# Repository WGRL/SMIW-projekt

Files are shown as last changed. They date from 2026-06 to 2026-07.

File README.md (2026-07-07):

Schematy i płytki PCB obejmują 3 projekty:
 - Moduł m5 Stamp-S3, zasilanie 12V i step downy na 5V i 3V3, potrzymanie akumulatorowe i ładowarkę opartą na LM317 + sterowanie źródłem zasilania
   Screenshot from 2026-07-08 00-59-42

 - Moduł czytnika kart micro sd (SPI) i pamięć FRAM
   Screenshot from 2026-07-08 01-00-04

 - Moduł sterowania silnikiem 12V, złącze silnika i enkoder
   Screenshot from 2026-07-08 00-59-53

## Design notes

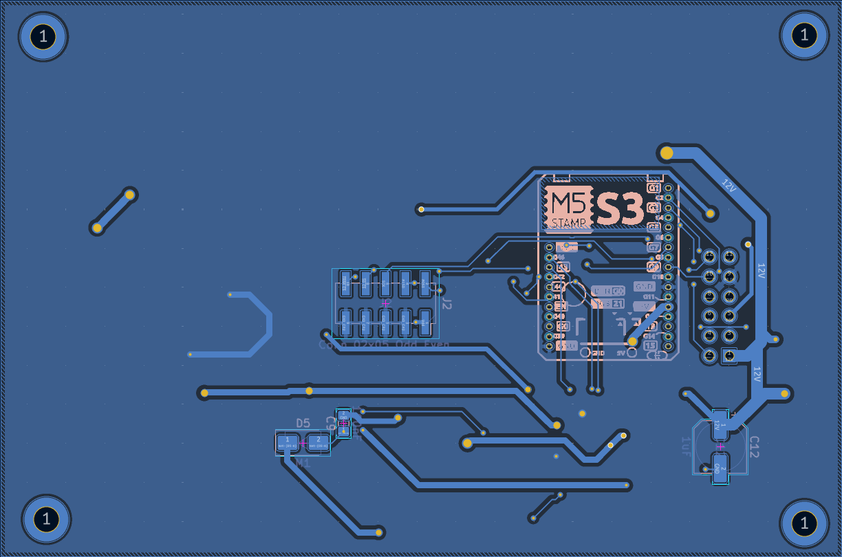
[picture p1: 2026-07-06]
img/PCB/Screenshot from 2026-07-06 23-42-25.png

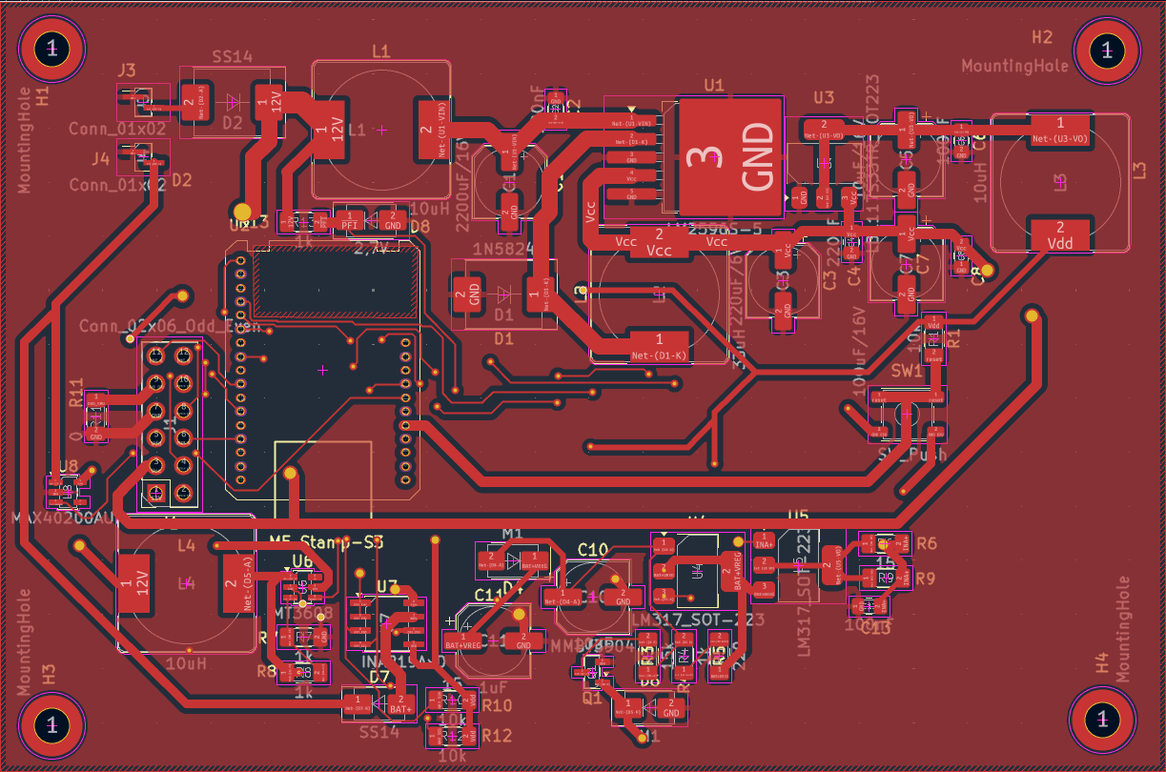
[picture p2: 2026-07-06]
img/PCB/Screenshot from 2026-07-06 23-42-44.png

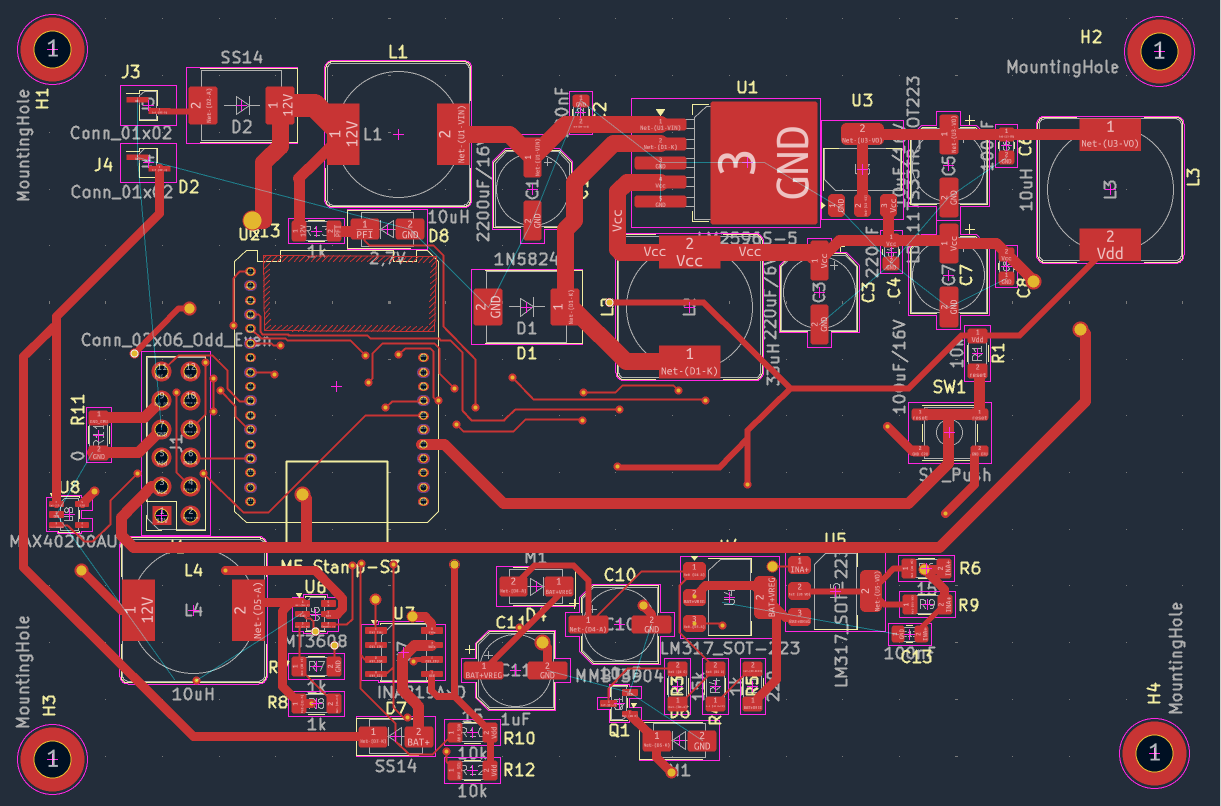
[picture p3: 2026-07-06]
img/PCB/Screenshot from 2026-07-06 23-42-52.png

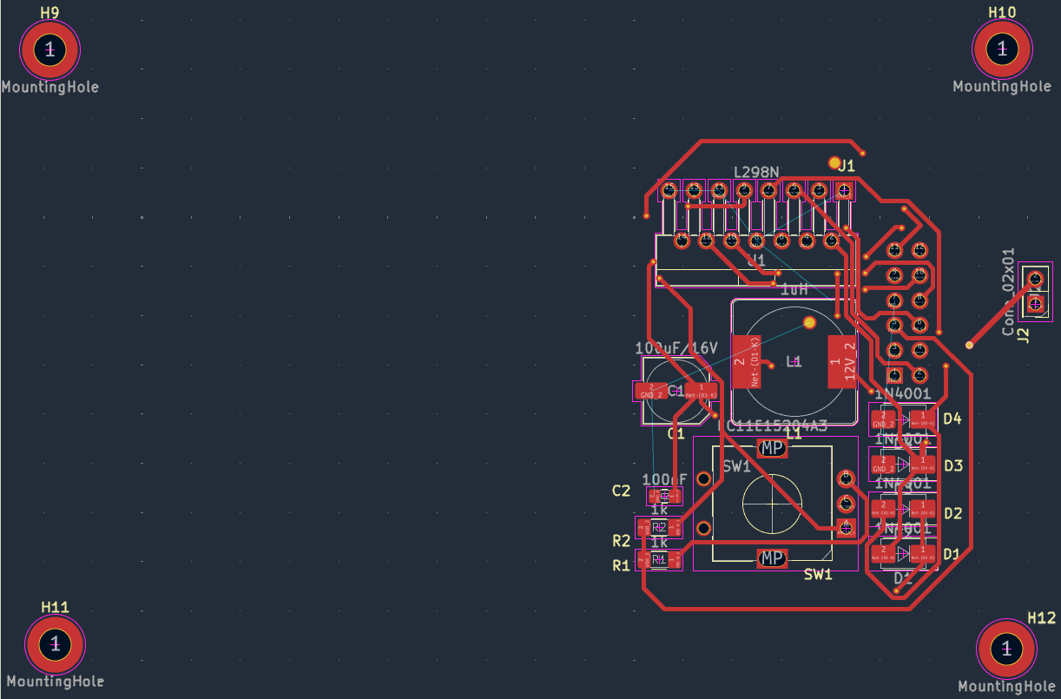
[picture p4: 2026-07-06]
img/PCB/Screenshot from 2026-07-06 23-41-21.png

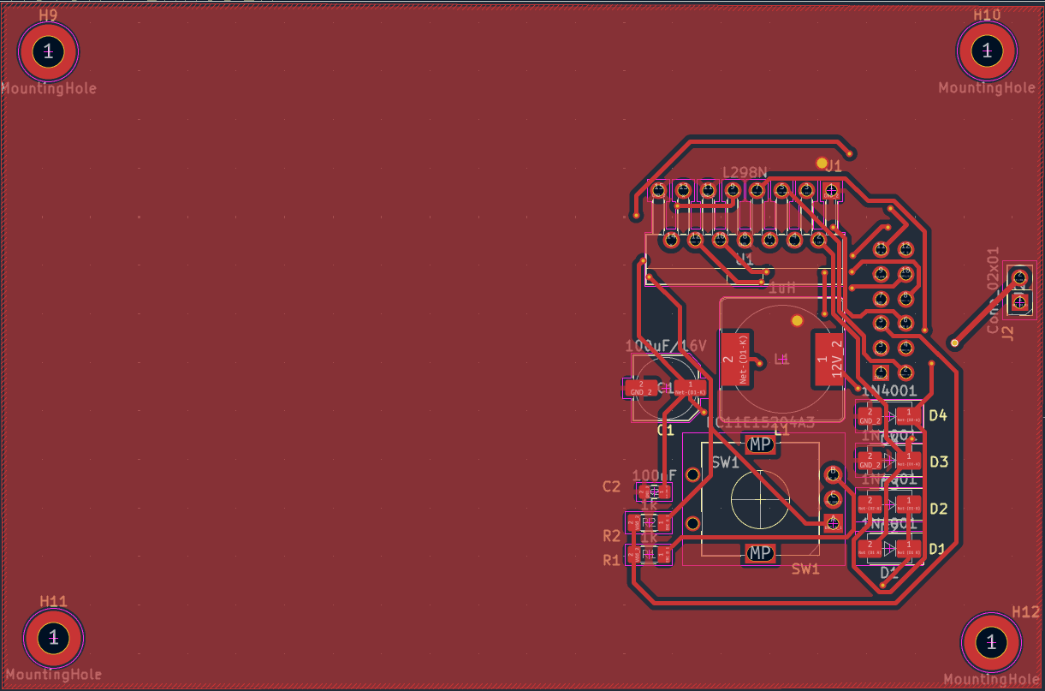
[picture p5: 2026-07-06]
img/PCB/Screenshot from 2026-07-06 23-41-01.png

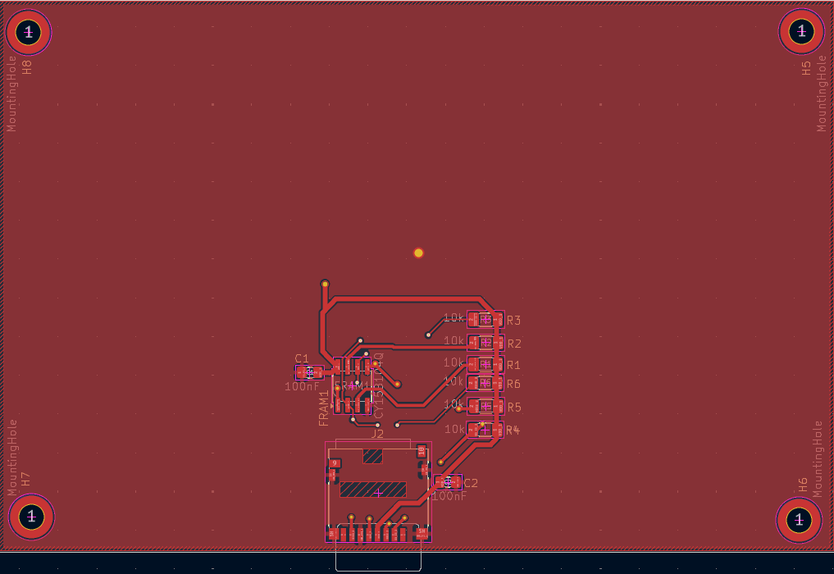
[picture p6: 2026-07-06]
img/PCB/Screenshot from 2026-07-06 23-43-59.png

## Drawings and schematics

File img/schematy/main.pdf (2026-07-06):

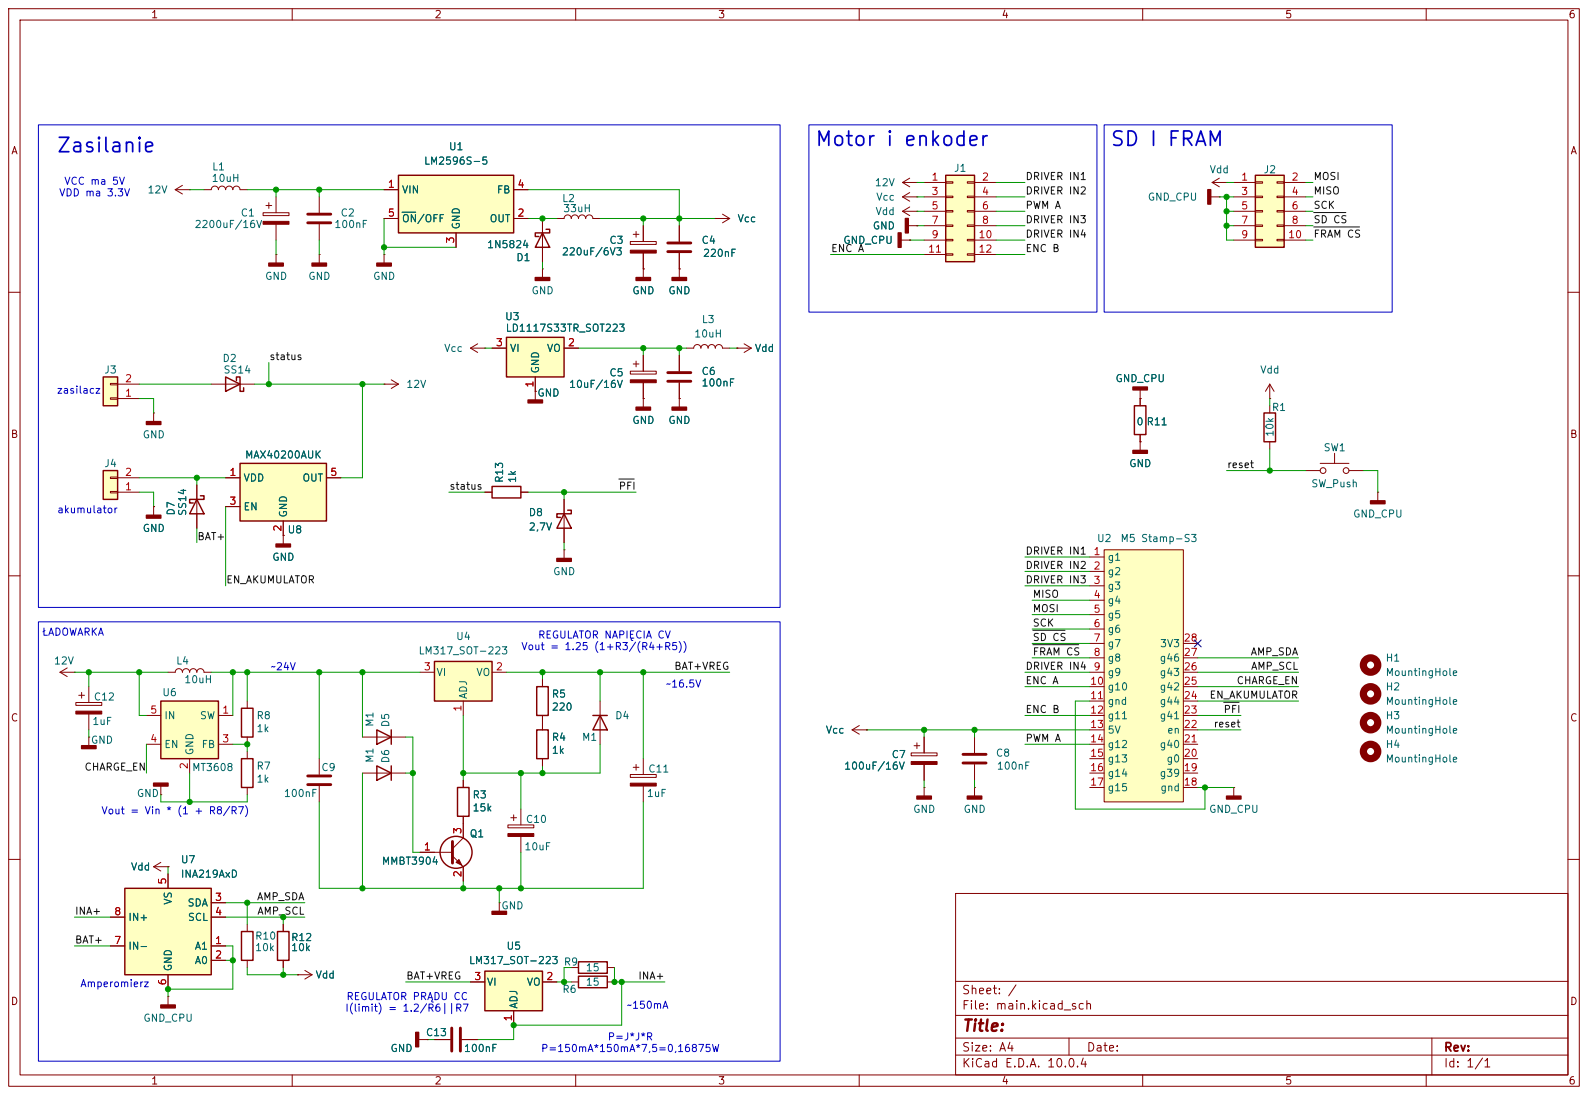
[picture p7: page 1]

Vout = 1.25 (1+R3/(R4+R5)) ~16.5V REGULATOR PRĄDU CC

Size: A4 | Rev:
KiCad E.D.A. 10.0.4 | Id: 1/1

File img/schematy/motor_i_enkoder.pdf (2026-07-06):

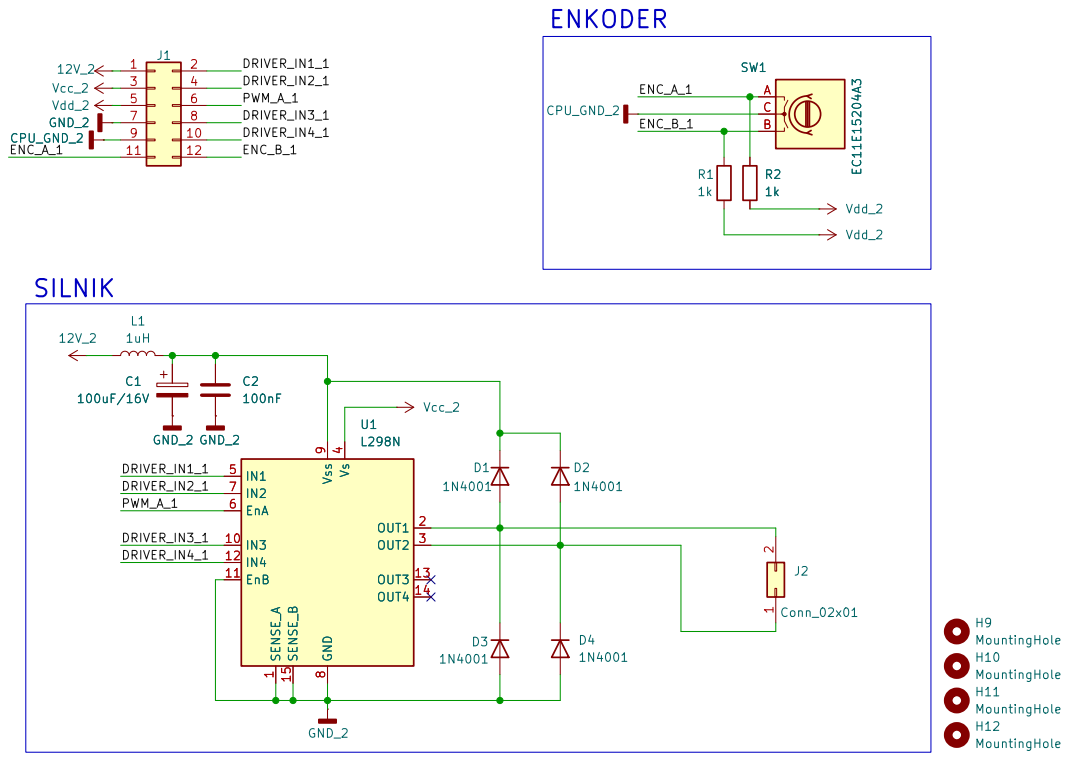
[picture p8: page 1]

Size: A4 | Rev:
KiCad E.D.A. 10.0.4 | Id: 3/1

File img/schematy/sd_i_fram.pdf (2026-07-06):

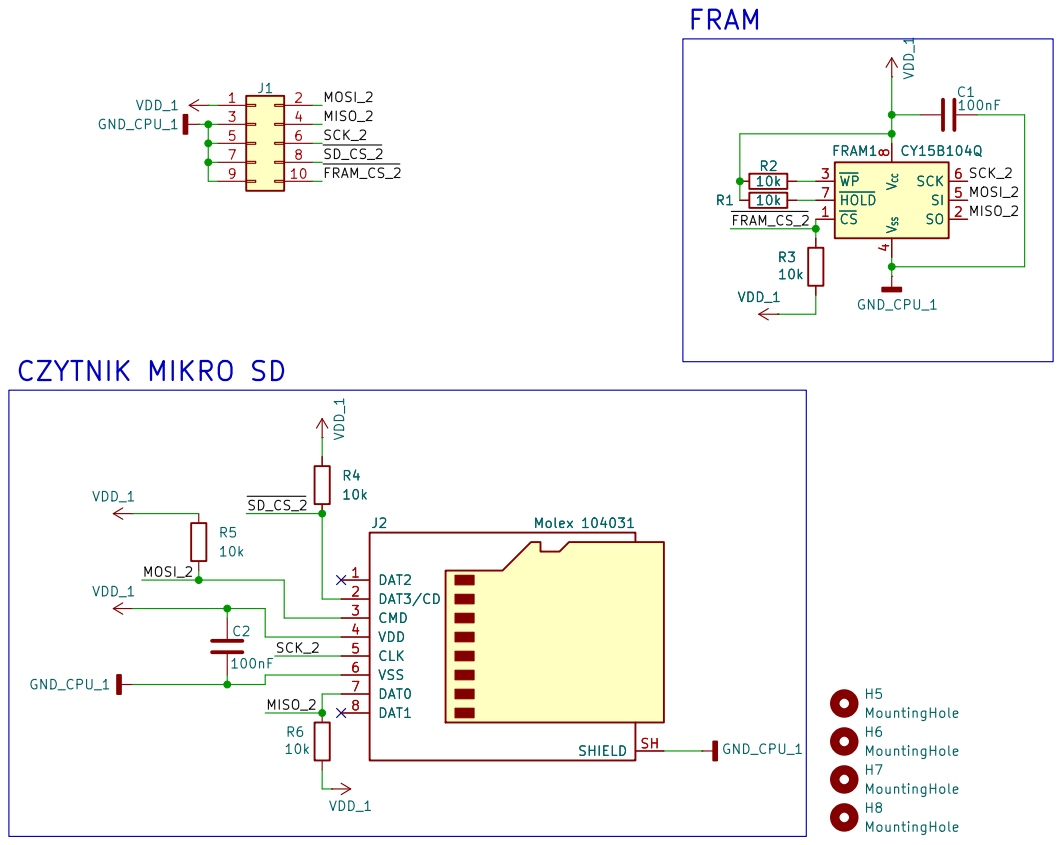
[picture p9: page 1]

Size: A4 | Rev:
KiCad E.D.A. 10.0.4 | Id: 2/1

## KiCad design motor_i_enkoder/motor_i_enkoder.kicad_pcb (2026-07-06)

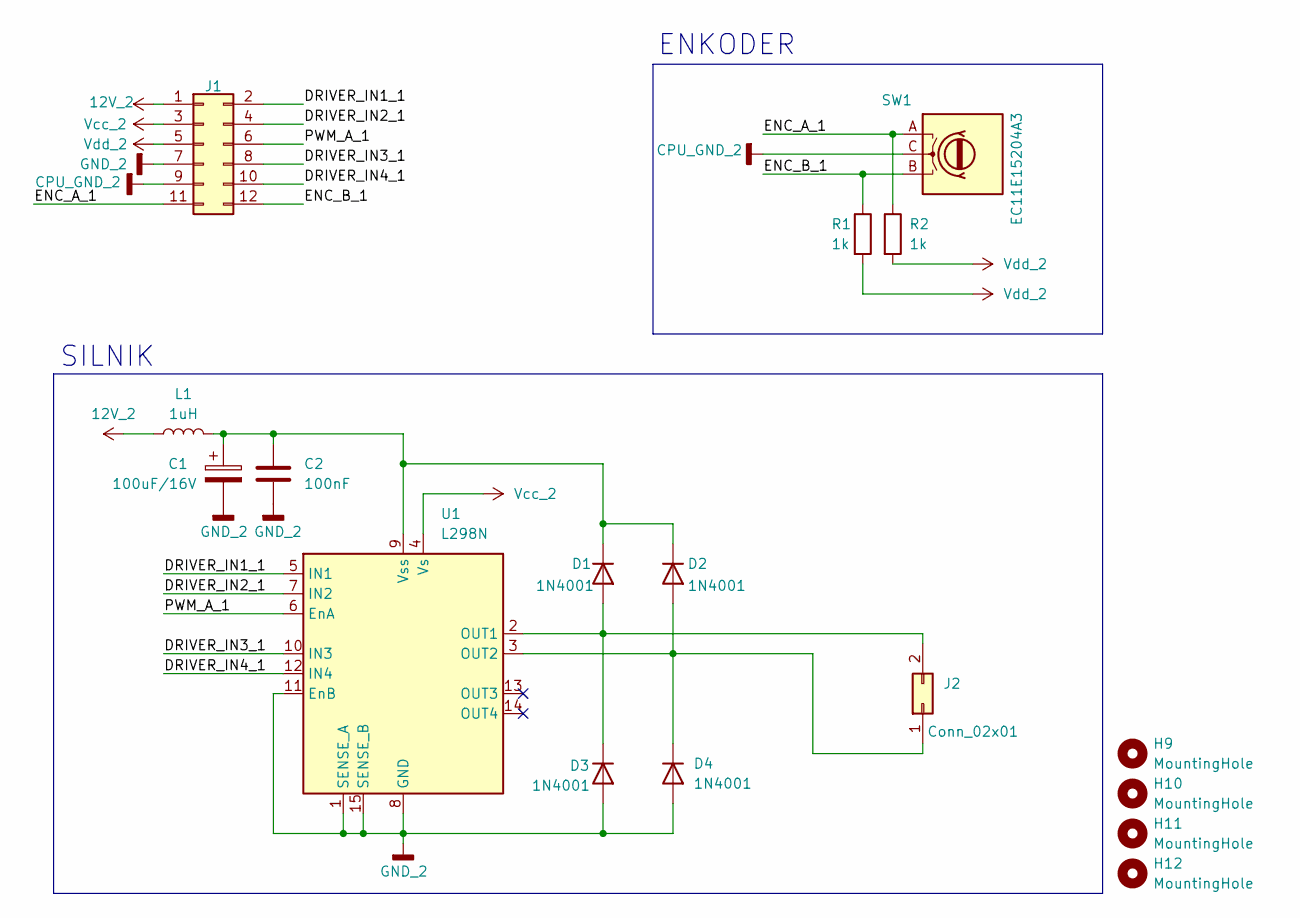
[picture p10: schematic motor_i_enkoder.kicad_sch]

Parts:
C1: 100uF/16V; C_Elec_6.3x7.7
C2: 100nF; C_0805_2012Metric_Pad1.18x1.45mm_HandSolder
D1, D2, D3, D4: 1N4001; D_SMA
H9, H10, H11, H12: MountingHole; MountingHole_3.2mm_M3_DIN965_Pad_TopBottom
J1: Conn_02x06_Odd_Even; PinHeader_2x06_P2.54mm_Vertical
J2: Conn_02x01; PinSocket_2x01_P2.54mm_Vertical
L1: 1uH; L_Bourns_SRR1260
R1, R2: 1k; R_1206_3216Metric_Pad1.30x1.75mm_HandSolder
SW1: EC11E15204A3; RotaryEncoder_Alps_EC11E_Vertical_H20mm
U1: L298N; TO-220-15_P2.54x5.08mm_StaggerOdd_Lead4.58mm_Vertical

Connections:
12V_2: J1.1, L1.1
/DRIVER_IN1_1: J1.2, U1.5 (IN1)
/DRIVER_IN2_1: J1.4, U1.7 (IN2)
/DRIVER_IN3_1: J1.8, U1.10 (IN3)
/DRIVER_IN4_1: J1.10, U1.12 (IN4)
/ENC_A_1: J1.11, R2.1, SW1.A
/ENC_B_1: J1.12, R1.1, SW1.B
/PWM_A_1: J1.6, U1.6 (EnA)
CPU_GND_2: J1.9, SW1.C
GND_2: C1.2, C2.2, D3.2 (A), D4.2 (A), J1.7, U1.1 (SENSE_A), U1.8 (GND), U1.11 (EnB), U1.15 (SENSE_B)
unnamed: D1.2 (A), D3.1 (K), J2.2, U1.2 (OUT1)
unnamed: C1.1, C2.1, D1.1 (K), D2.1 (K), L1.2, U1.9 (Vss)
unnamed: D2.2 (A), D4.1 (K), J2.1, U1.3 (OUT2)
Vcc_2: J1.3, U1.4 (Vs)
Vdd_2: J1.5, R1.2, R2.2

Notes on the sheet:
SILNIK
ENKODER

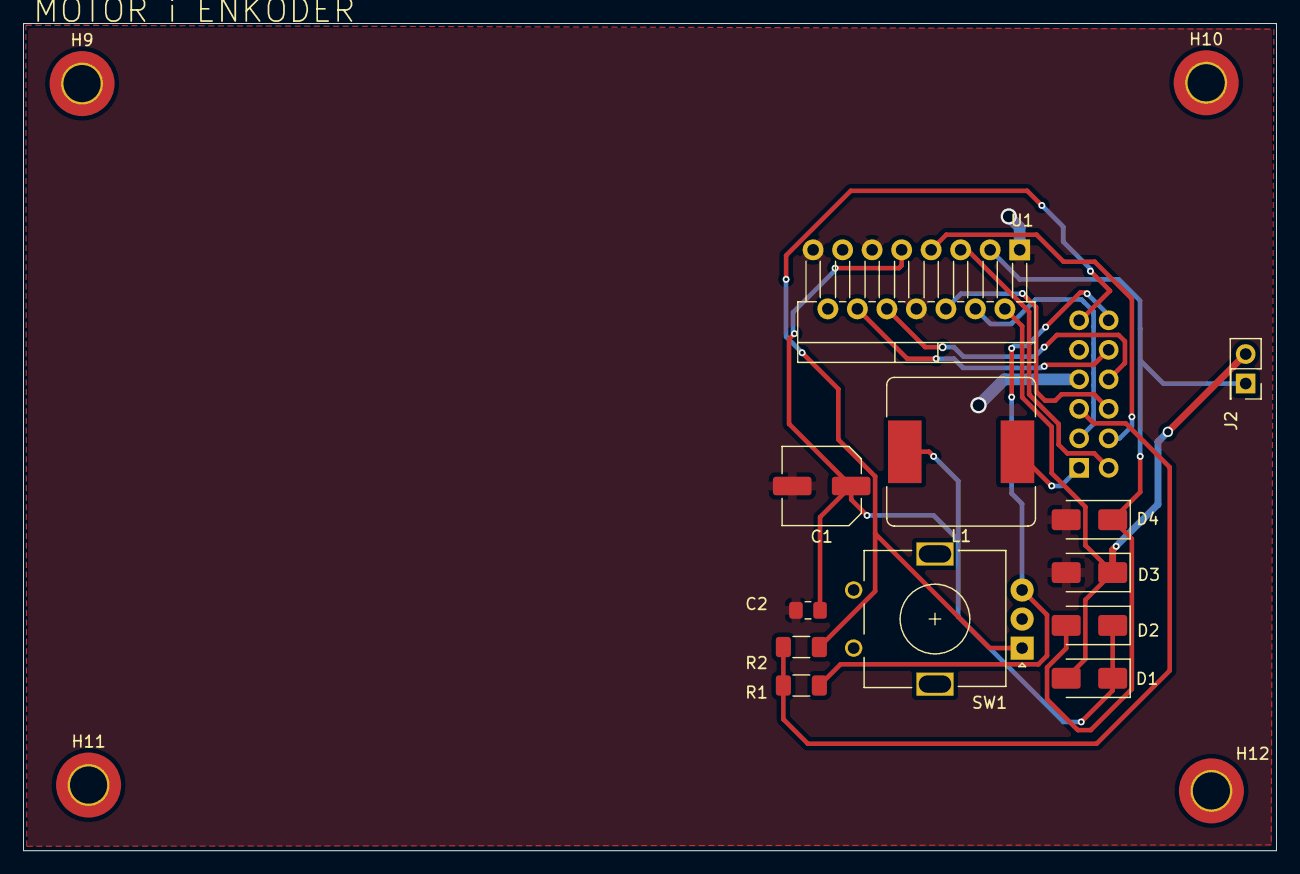
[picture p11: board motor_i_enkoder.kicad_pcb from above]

Board: 2 copper layers, 107.8 x 71.2 mm, 17 parts (1 on the bottom side), 15 nets.

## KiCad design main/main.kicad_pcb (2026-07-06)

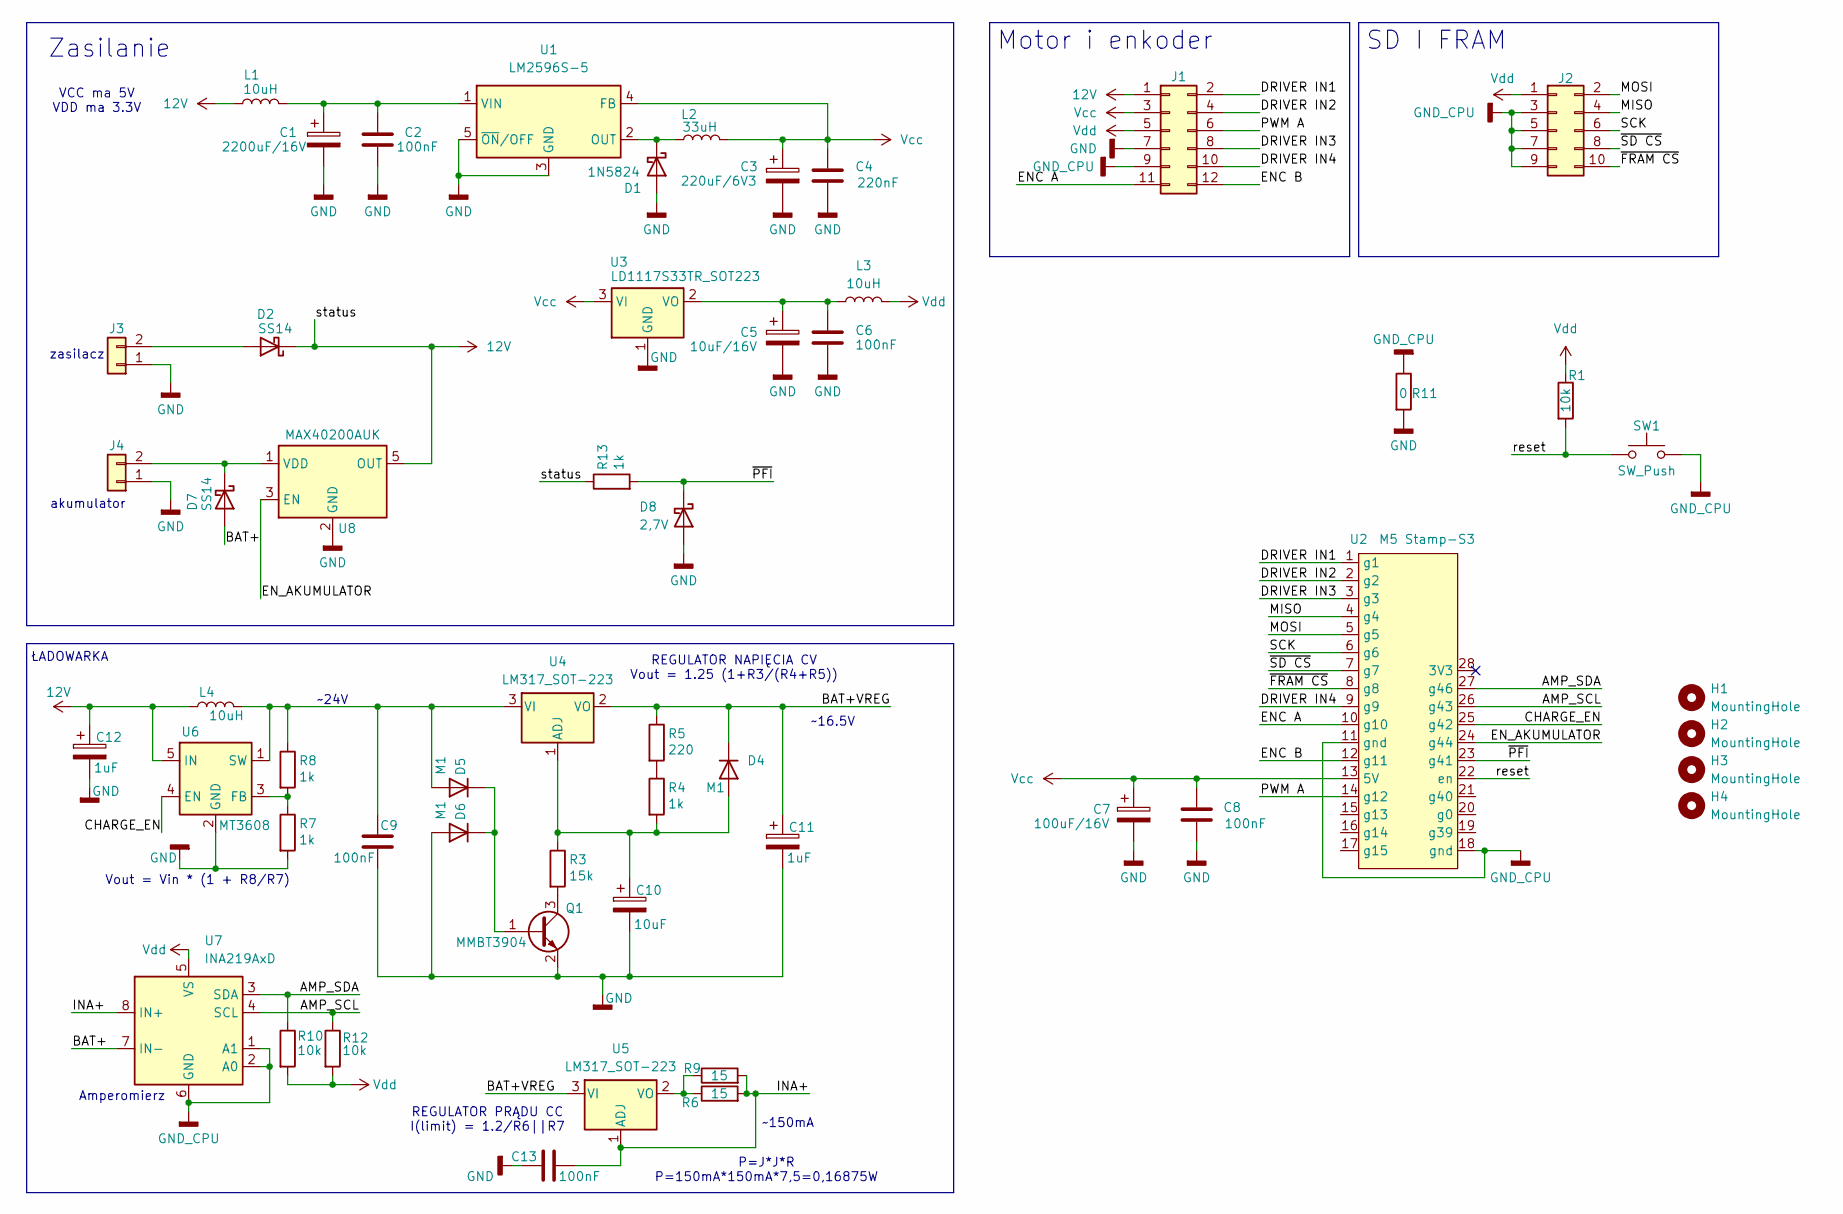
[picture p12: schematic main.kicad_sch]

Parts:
C1: 2200uF/16V; CP_Elec_6.3x5.3
C2, C6, C8, C9, C13: 100nF; C_0805_2012Metric_Pad1.18x1.45mm_HandSolder
C3: 220uF/6V3; CP_Elec_6.3x5.3
C4: 220nF; C_0805_2012Metric_Pad1.18x1.45mm_HandSolder
C5: 10uF/16V; CP_Elec_6.3x5.3
C7: 100uF/16V; CP_Elec_6.3x5.3
C10: 10uF; CP_Elec_6.3x5.3
C11, C12: 1uF; CP_Elec_6.3x5.3
D1: 1N5824; D_SMC
D2: SS14; D_SMC
D4, D5, D6: M1; D_SMA
D7: SS14; D_SMA
D8: 2,7V; D_SMA
H1, H2, H3, H4: MountingHole; MountingHole_3.2mm_M3_DIN965_Pad_TopBottom
J1: Conn_02x06_Odd_Even; PinSocket_2x06_P2.54mm_Vertical
J2: Conn_02x05_Odd_Even; PinSocket_2x05_P2.54mm_Vertical_SMD
J3, J4: Conn_01x02; PinSocket_1x02_P1.00mm_Vertical_SMD_Pin1Left
L1, L3, L4: 10uH; L_Bourns_SRR1260
L2: 33uH; L_Bourns_SRR1260
Q1: MMBT3904; SOT-23
R1, R10, R12: 10k; R_1206_3216Metric_Pad1.30x1.75mm_HandSolder
R3: 15k; R_1206_3216Metric_Pad1.30x1.75mm_HandSolder
R4, R7, R8, R13: 1k; R_1206_3216Metric_Pad1.30x1.75mm_HandSolder
R5: 220; R_1206_3216Metric_Pad1.30x1.75mm_HandSolder
R6, R9: 15; R_1206_3216Metric_Pad1.30x1.75mm_HandSolder
R11: 0; R_1206_3216Metric_Pad1.30x1.75mm_HandSolder
SW1: SW_Push; SW_SPST_PTS647_Sx50
U1: LM2596S-5; TO-263-5_TabPin3
U2: M5 Stamp-S3; Stamp-S3-DIP
U3: LD1117S33TR_SOT223; SOT-223-3_TabPin2
U4, U5: LM317_SOT-223; SOT-223-3_TabPin2
U6: MT3608; SOT-23-6
U7: INA219AxD; SOIC-8_3.9x4.9mm_P1.27mm
U8: MAX40200AUK; SOT-23-5

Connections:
12V: C12.1, D2.1 (K), J1.1, L1.1, L4.1, R13.1, U6.5 (IN), U8.5 (OUT)
/AMP_SCL: R12.1, U2.26 (g43), U7.4 (SCL)
/AMP_SDA: R10.1, U2.27 (g46), U7.3 (SDA)
/BAT+: D7.2 (A), U7.7 (IN-)
/BAT+VREG: C11.1, D4.1 (K), R5.1, U4.2 (VO), U5.3 (VI)
/CHARGE_EN: U2.25 (g42), U6.4 (EN)
/DRIVER IN1: J1.2, U2.1 (g1)
/DRIVER IN2: J1.4, U2.2 (g2)
/DRIVER IN3: J1.8, U2.3 (g3)
/DRIVER IN4: J1.10, U2.9 (g9)
/ENC A: J1.11, U2.10 (g10)
/ENC B: J1.12, U2.12 (g11)
/EN_AKUMULATOR: U2.24 (g44), U8.3 (EN)
/INA+: C13.2, R6.2, R9.2, U5.1 (ADJ), U7.8 (IN+)
/MISO: J2.4, U2.4 (g4)
/MOSI: J2.2, U2.5 (g5)
/PWM A: J1.6, U2.14 (g12)
/SCK: J2.6, U2.6 (g6)
/reset: R1.2, SW1.1, U2.22 (en)
/~FRAM CS: J2.10, U2.8 (g8)
/~PFI: D8.1 (K), R13.2, U2.23 (g41)
/~SD CS: J2.8, U2.7 (g7)
GND: C1.2, C2.1, C3.2, C4.2, C5.2, C6.2, C7.2, C8.1, C9.2, C10.2, C11.2, C12.2, C13.1, D1.2 (A), D6.2 (A), D8.2 (A), J1.7, J3.1, J4.1, Q1.2 (E), R7.2, R11.2, U1.3 (GND), U1.5 (~ON/OFF), U3.1 (GND), U6.2 (GND), U8.2 (GND)
GND_CPU: J1.9, J2.3, J2.5, J2.7, J2.9, R11.1, SW1.2, U2.11 (gnd), U2.18 (gnd), U7.1 (A1), U7.2 (A0), U7.6 (GND)
unnamed: D1.1 (K), L2.1, U1.2 (OUT)
unnamed: D2.2 (A), J3.2
unnamed: C10.1, D4.2 (A), R3.1, R4.2, U4.1 (ADJ)
unnamed: C9.1, D5.2 (A), L4.2, R8.1, U4.3 (VI), U6.1 (SW)
unnamed: D5.1 (K), D6.1 (K), Q1.1 (B)
unnamed: D7.1 (K), J4.2, U8.1 (VDD)
unnamed: Q1.3 (C), R3.2
unnamed: R4.1, R5.2
unnamed: C1.1, C2.2, L1.2, U1.1 (VIN)
unnamed: C5.1, C6.1, L3.1, U3.2 (VO)
unnamed: R6.1, R9.1, U5.2 (VO)
unnamed: R7.1, R8.2, U6.3 (FB)
Vcc: C3.1, C4.1, C7.1, C8.2, J1.3, L2.2, U1.4 (FB), U2.13 (5V), U3.3 (VI)
Vdd: J1.5, J2.1, L3.2, R1.1, R10.2, R12.2, U7.5 (VS)

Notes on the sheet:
ŁADOWARKA
zasilacz
REGULATOR NAPIĘCIA CV Vout = 1.25 (1+R3/(R4+R5))
Vout = Vin * (1 + R8/R7)
akumulator
REGULATOR PRĄDU CC I(limit) = 1.2/R6||R7
VCC ma 5V VDD ma 3.3V
Zasilanie
~24V
~150mA
Amperomierz
P=J*J*R P=150mA*150mA*7,5=0,16875W
~16.5V
Motor i enkoder
SD I FRAM

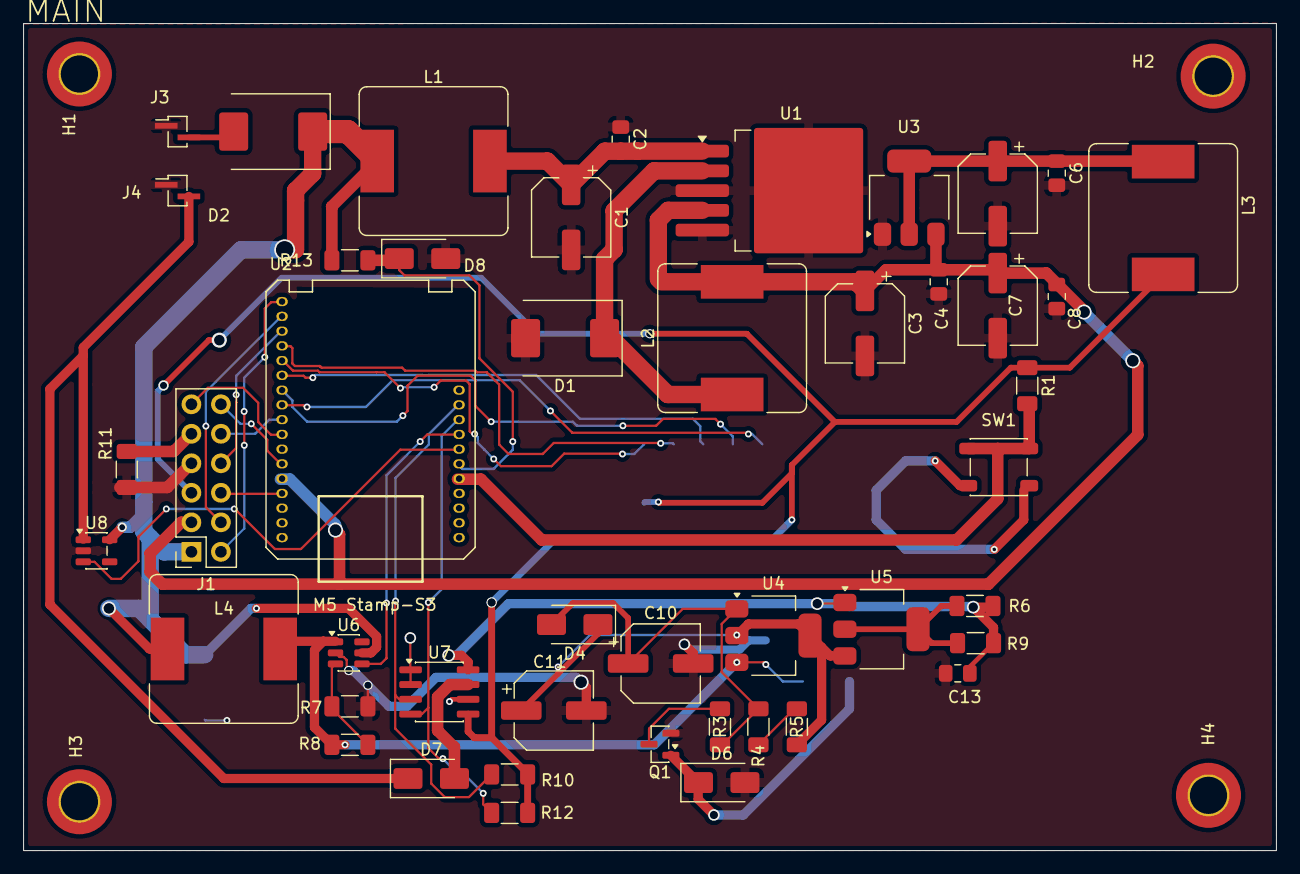
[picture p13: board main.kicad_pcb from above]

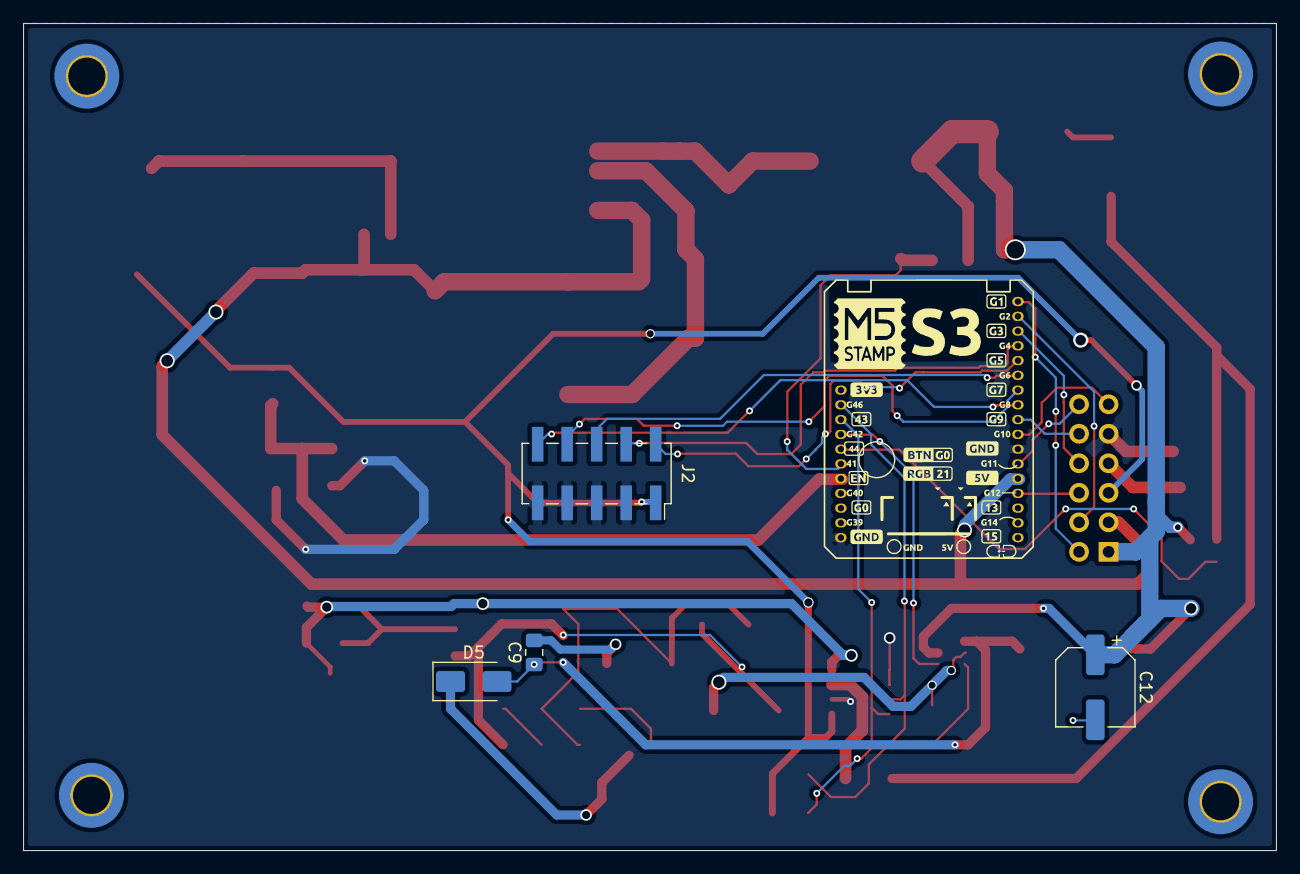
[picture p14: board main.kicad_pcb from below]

Board: 2 copper layers, 107.8 x 71.2 mm, 54 parts (4 on the bottom side), 38 nets.

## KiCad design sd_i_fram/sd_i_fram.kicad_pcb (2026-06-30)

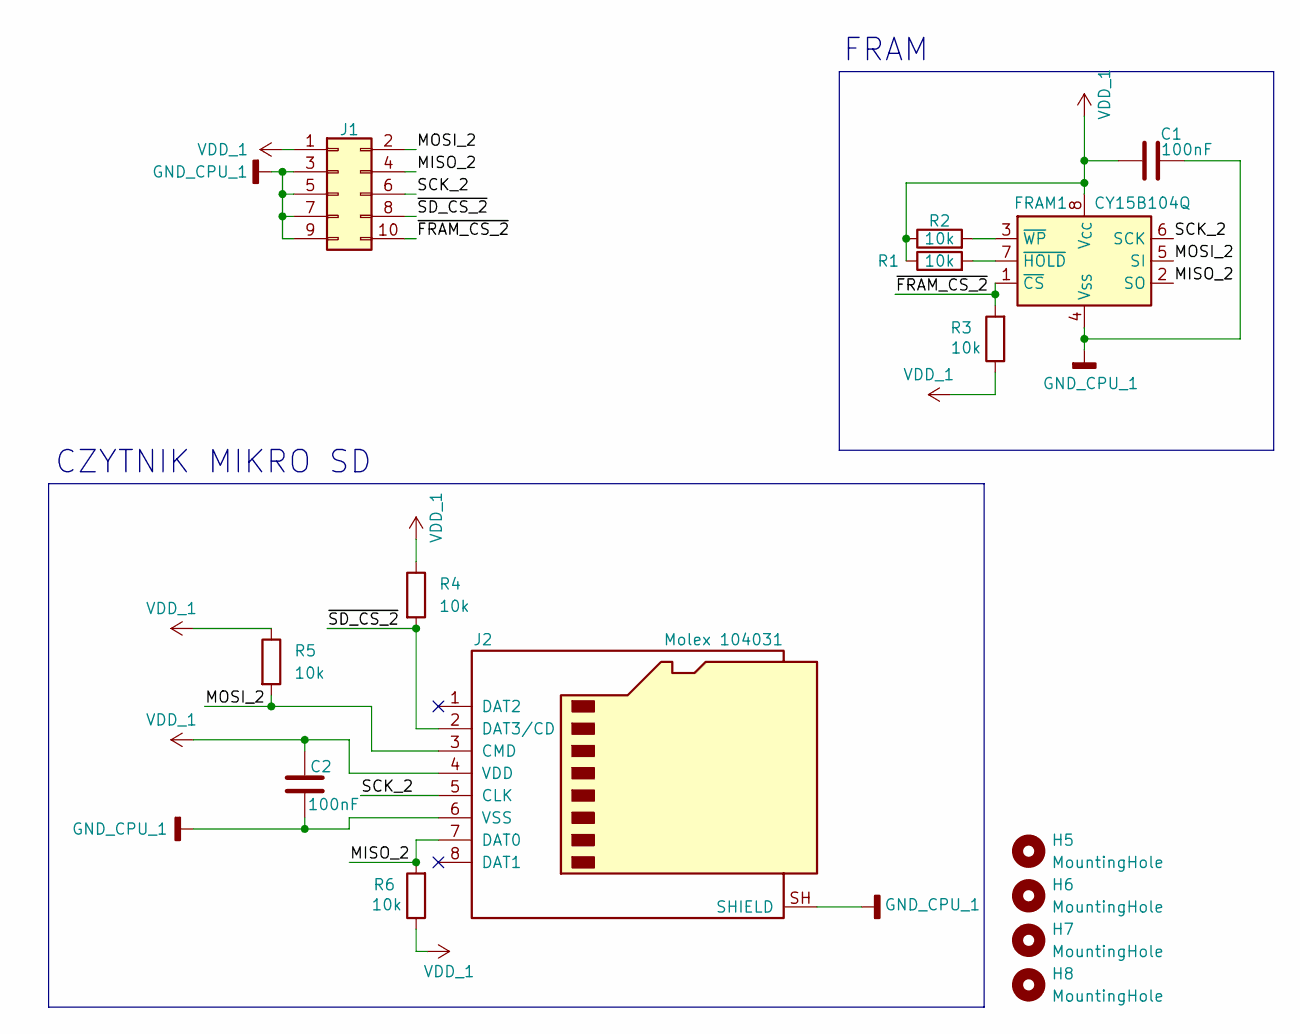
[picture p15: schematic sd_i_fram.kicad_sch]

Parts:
C1, C2: 100nF; C_0805_2012Metric_Pad1.18x1.45mm_HandSolder
FRAM1: CY15B104Q; SOIC-8_3.9x4.9mm_P1.27mm
H5, H6, H7, H8: MountingHole; MountingHole_3.2mm_M3_DIN965_Pad_TopBottom
J1: Conn_02x05_Odd_Even; PinHeader_2x05_P2.54mm_Vertical_SMD
J2: Molex 104031; microSD_HC_Hirose_DM3D-SF
R1, R2, R3, R4, R5, R6: 10k; R_1206_3216Metric_Pad1.30x1.75mm_HandSolder

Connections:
/MISO_2: FRAM1.2 (SO), J1.4, J2.7 (DAT0), R6.2
/MOSI_2: FRAM1.5 (SI), J1.2, J2.3 (CMD), R5.2
/SCK_2: FRAM1.6 (SCK), J1.6, J2.5 (CLK)
/~FRAM_CS_2: FRAM1.1 (~CS), J1.10, R3.2
/~SD_CS_2: J1.8, J2.2 (DAT3/CD), R4.2
GND_CPU_1: C1.1, C2.2, FRAM1.4 (V_{SS}), J1.3, J1.5, J1.7, J1.9, J2.6 (VSS), J2.SH (SHIELD)
unnamed: FRAM1.7 (~HOLD), R2.2
unnamed: FRAM1.3 (~WP), R1.2
VDD_1: C1.2, C2.1, FRAM1.8 (V_{CC}), J1.1, J2.4 (VDD), R1.1, R2.1, R3.1, R4.1, R5.1, R6.1

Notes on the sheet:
FRAM
CZYTNIK MIKRO SD

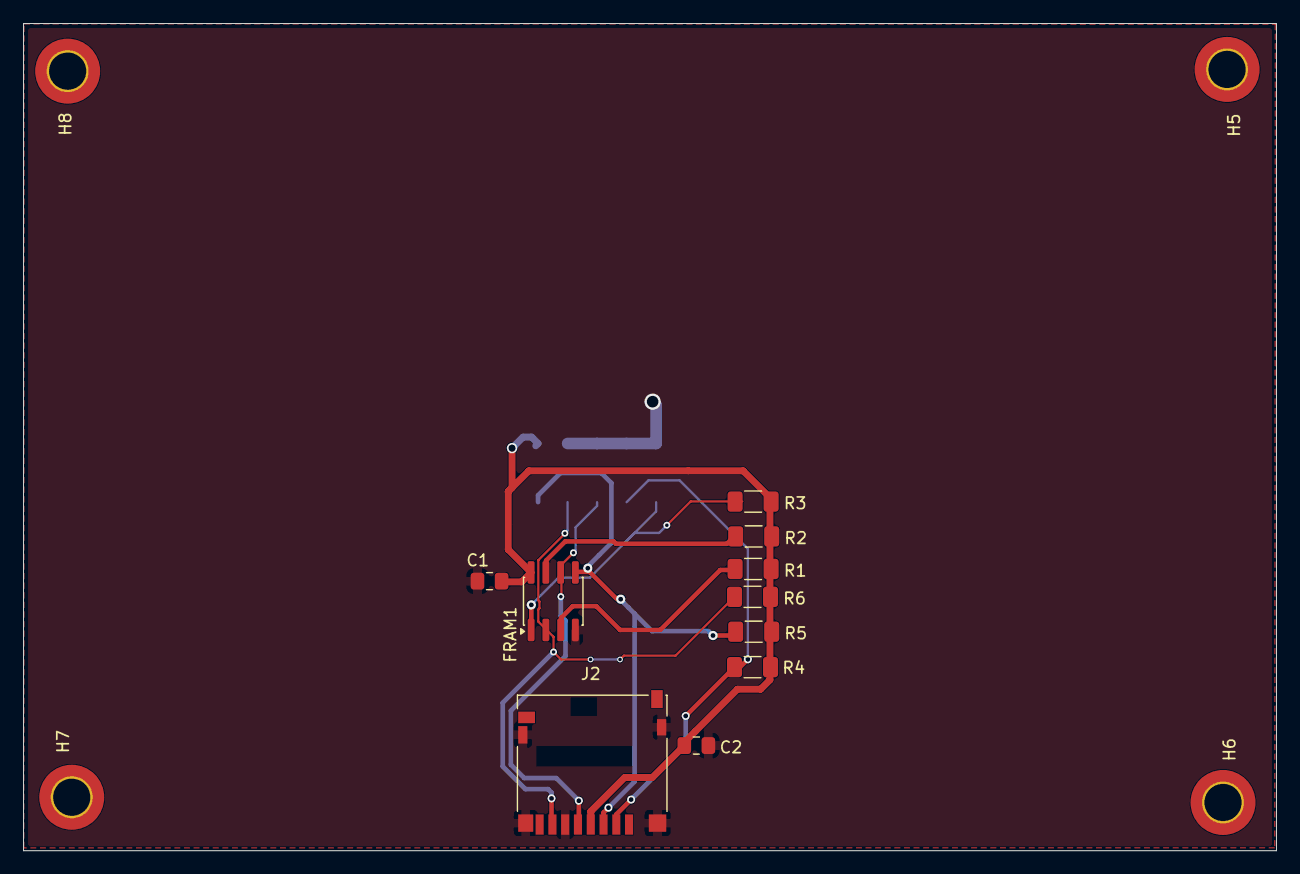
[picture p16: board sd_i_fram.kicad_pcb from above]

Board: 2 copper layers, 107.9 x 71.2 mm, 15 parts (1 on the bottom side), 9 nets.

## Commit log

2026-06-14 pcb dobrze zdaniem michala (to nie ma sensu)
    [smiw_proj.kicad_pcb, smiw_proj.kicad_sch]
2026-06-14 wszystko powinno dzialac. Trzeba zrobic podzial
    [motor_i_enkoder.kicad_sch, sd_i_fram.kicad_sch, smiw_proj.kicad_pcb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]
2026-06-25 poprawione pcb. Dodana poprawka w silniku po konsultacjach
    [main.kicad_pcb, main.kicad_sch, motor_i_enkoder.kicad_pcb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]
2026-06-30 resized. Kanapka
    [main.kicad_pcb, motor_i_enkoder.kicad_pcb, sd_i_fram.kicad_pcb]
2026-07-06 zatwierdzone sprawko
    [main.kicad_pcb, motor_i_enkoder.kicad_pcb]
